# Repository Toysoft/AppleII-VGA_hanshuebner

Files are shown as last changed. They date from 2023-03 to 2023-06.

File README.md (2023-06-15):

# ∀2 Retro Computing Analog VGA Card & PicoPal
PicoPal Logo

This is a fork of
[David Kuder's version](https://github.com/V2RetroComputing/analog) of
[Mark Aikens' Apple II VGA](https://github.com/markadev/AppleII-VGA/)
project.

The goal of this fork is to make the board cheaper and easier to
produce.  It is now a 2 layer instead of a 4 layer PCB, uses cheaper
bus transceivers and 0603 passive components that are easier to work
with when building the board by hand.

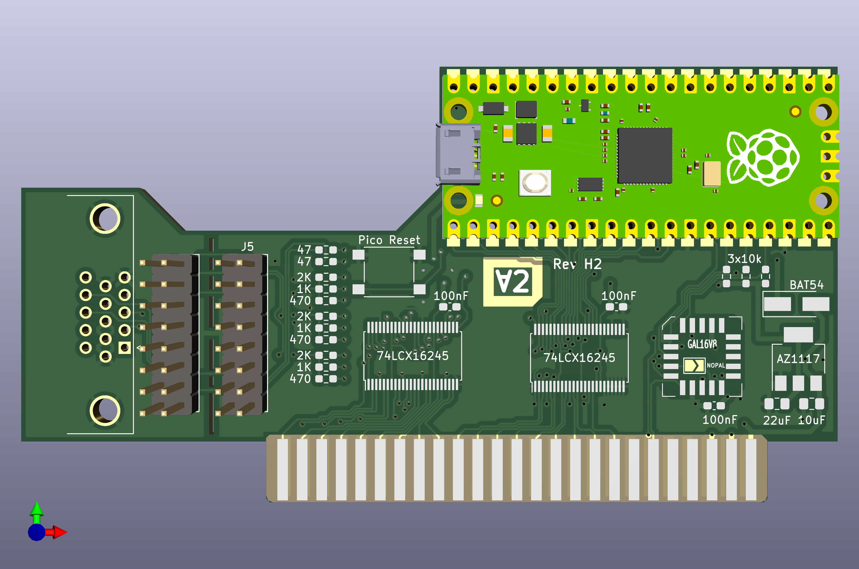
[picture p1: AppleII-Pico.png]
PCB Rendering


The board provides a VGA output to Apple II compatible machines.  It works by
snooping the bus activity and capturing what is written to the internal
graphics hardware.  This is used to render an additional image into a
framebuffer on the Raspberry Pi Pico.  That framebuffer is output
to a standard VGA compatible output.

The VGA emulation starts up with a test screen.  Reset your Apple to
go to the BASIC prompt or boot screen.

The footprint of the VGA IDC connector on the board is incorrect.  The
red wire of the ribbon cable must be facing down, in direction of the 
motherboard.  If you get no picture, try rotating the cable.

Alternatively, the card can run a Z80 emulation in software, emulating
a standard Z80 softcard.  To use that mode, the Raspberry Pi Pico must
be re-flashed.

Please use
[GitHub Issues](https://github.com/hanshuebner/AppleII-VGA/issues) to
provide feedback.  THANK YOU!

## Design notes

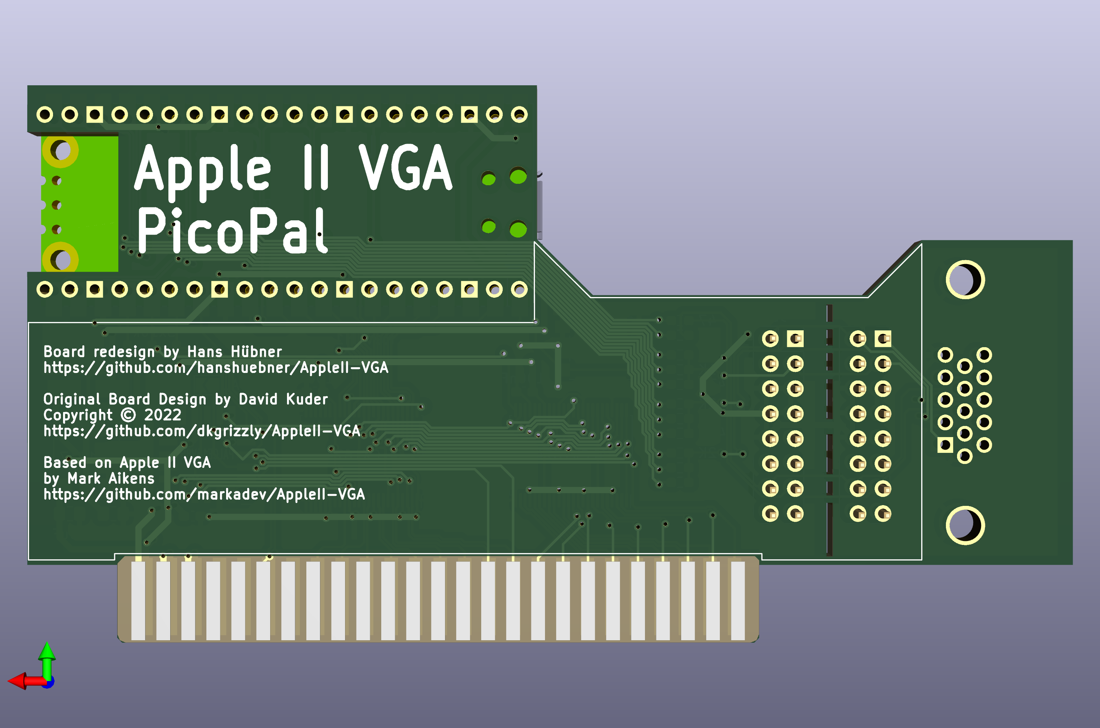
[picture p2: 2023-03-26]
docs/AppleII-Pico-back.png

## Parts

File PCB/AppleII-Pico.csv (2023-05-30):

Comment | Designator | Footprint | LCSC
100nF | C1,C2,C3 | Capacitor_SMD:C_0603_1608Metric_Pad1.08x0.95mm_HandSolder | C2857981
22uF | C10 | Capacitor_SMD:C_0805_2012Metric_Pad1.18x1.45mm_HandSolder | C5181863
10uF | C11 | Capacitor_SMD:C_0805_2012Metric_Pad1.18x1.45mm_HandSolder | C123608
BAT54 | D1 | Diode_SMD:D_SMA_Handsoldering | C5204731
Apple II | J1 | STDBUS:AppleII
DB15_Female_HighDensity_MountingHoles | J2 | Connector_Dsub:DSUB-15-HD_Female_Horizontal_P2.29x1.98mm_EdgePinOffset3.03mm_Housed_MountingHolesOffset4.94mm
NOGAL | J3 | Jumper:SolderJumper-2_P1.3mm_Open_TrianglePad1.0x1.5mm
VGA | J4,J5 | Connector_PinHeader_2.54mm:PinHeader_2x08_P2.54mm_Vertical
470 | R1,R4,R7 | Resistor_SMD:R_0603_1608Metric_Pad0.98x0.95mm_HandSolder | C103660
47 | R10,R11 | Resistor_SMD:R_0603_1608Metric_Pad0.98x0.95mm_HandSolder | C3016437
10K | R12,R13,R14 | Resistor_SMD:R_0603_1608Metric_Pad0.98x0.95mm_HandSolder | C3017715
1K | R2,R5,R8 | Resistor_SMD:R_0603_1608Metric_Pad0.98x0.95mm_HandSolder | C3016283
2K | R3,R6,R9 | Resistor_SMD:R_0603_1608Metric_Pad0.98x0.95mm_HandSolder | C3016472
Pico Reset | SW1 | Button_Switch_SMD:SW_Push_1P1T_NO_6x6mm_H9.5mm | C5381239
74LCX16245 | U1 | Package_SO:TSSOP-48_6.1x9.7mm_P0.4mm | C894789
74LCX16245 | U2 | Package_SO:TSSOP-48_6.1x12.5mm_P0.5mm | C894789
GAL16V8 | U5 | Package_LCC:PLCC-20
Pi PICO | U6 | MCU_RaspberryPi_and_Boards:RPi_Pico_SMD_TH
AZ1117-3.3 | U7 | Package_TO_SOT_SMD:SOT-223-3_TabPin2 | C110474

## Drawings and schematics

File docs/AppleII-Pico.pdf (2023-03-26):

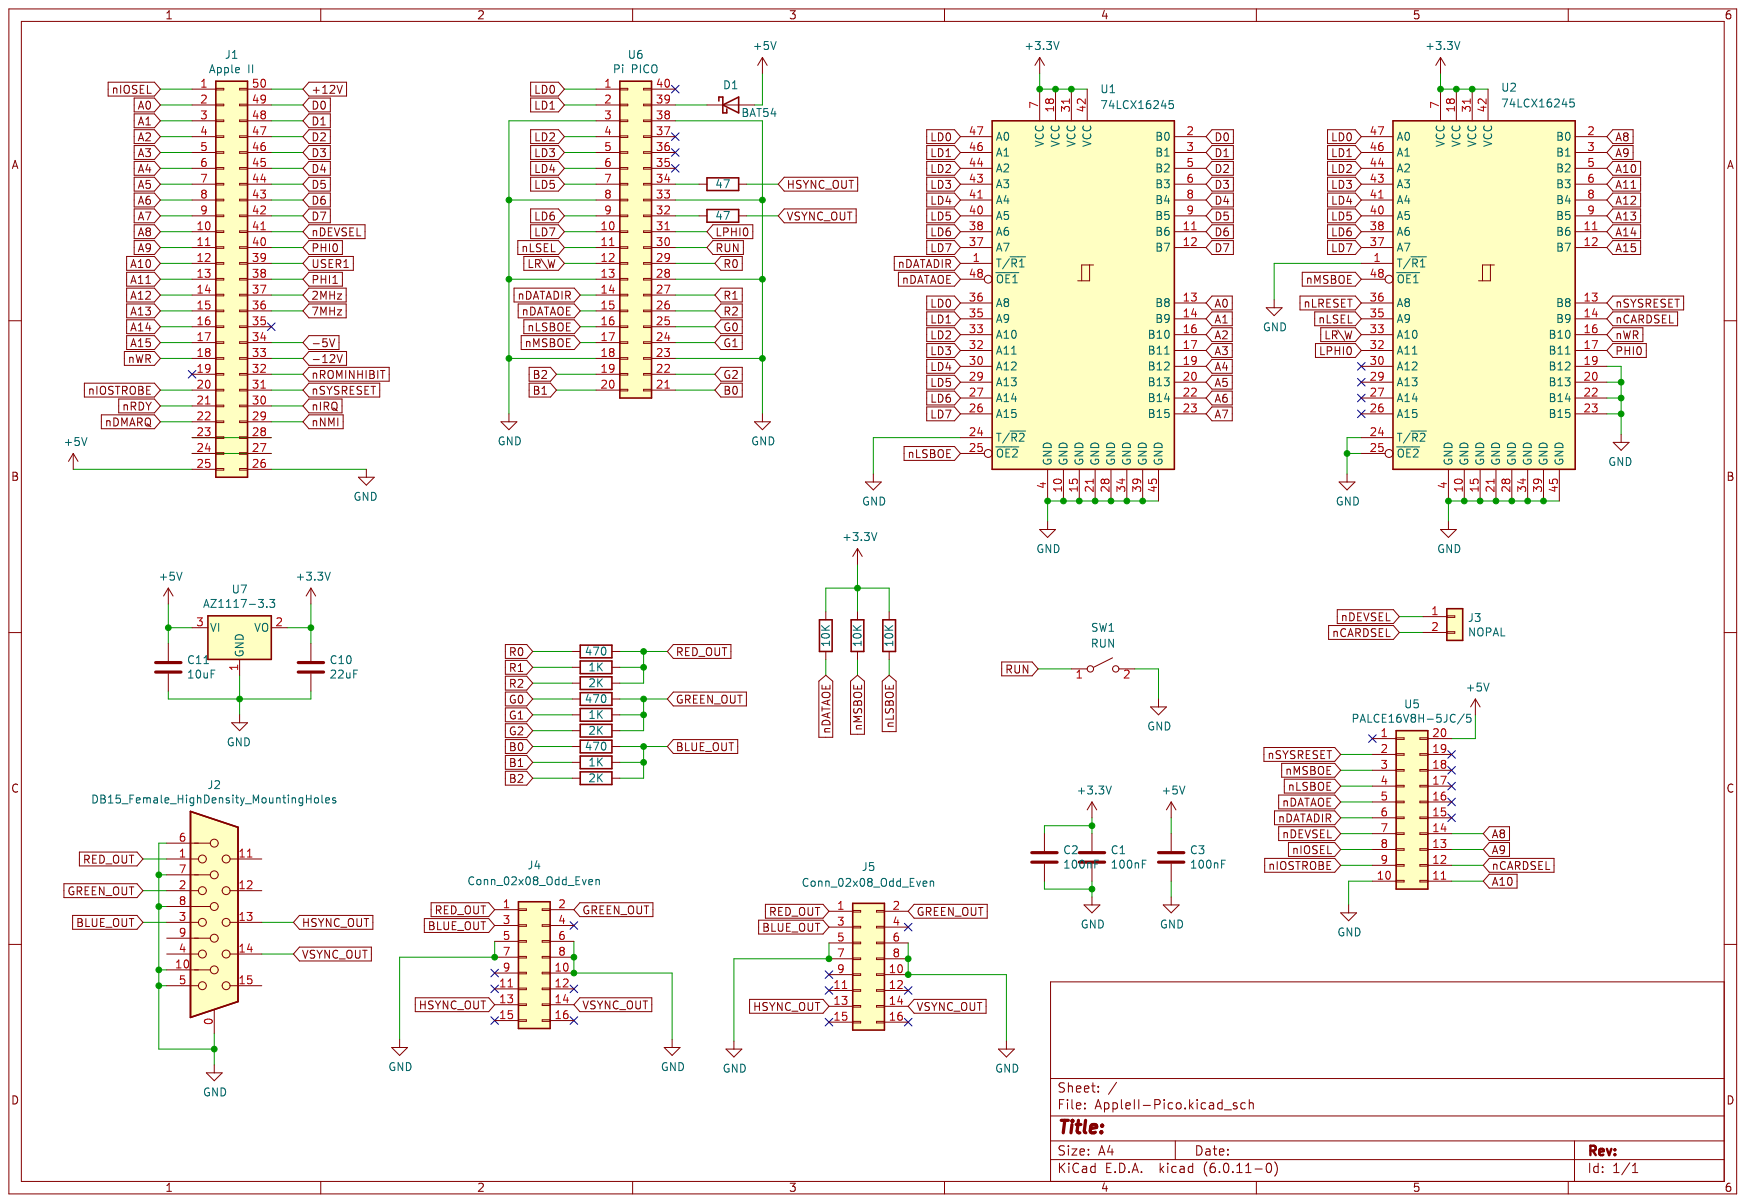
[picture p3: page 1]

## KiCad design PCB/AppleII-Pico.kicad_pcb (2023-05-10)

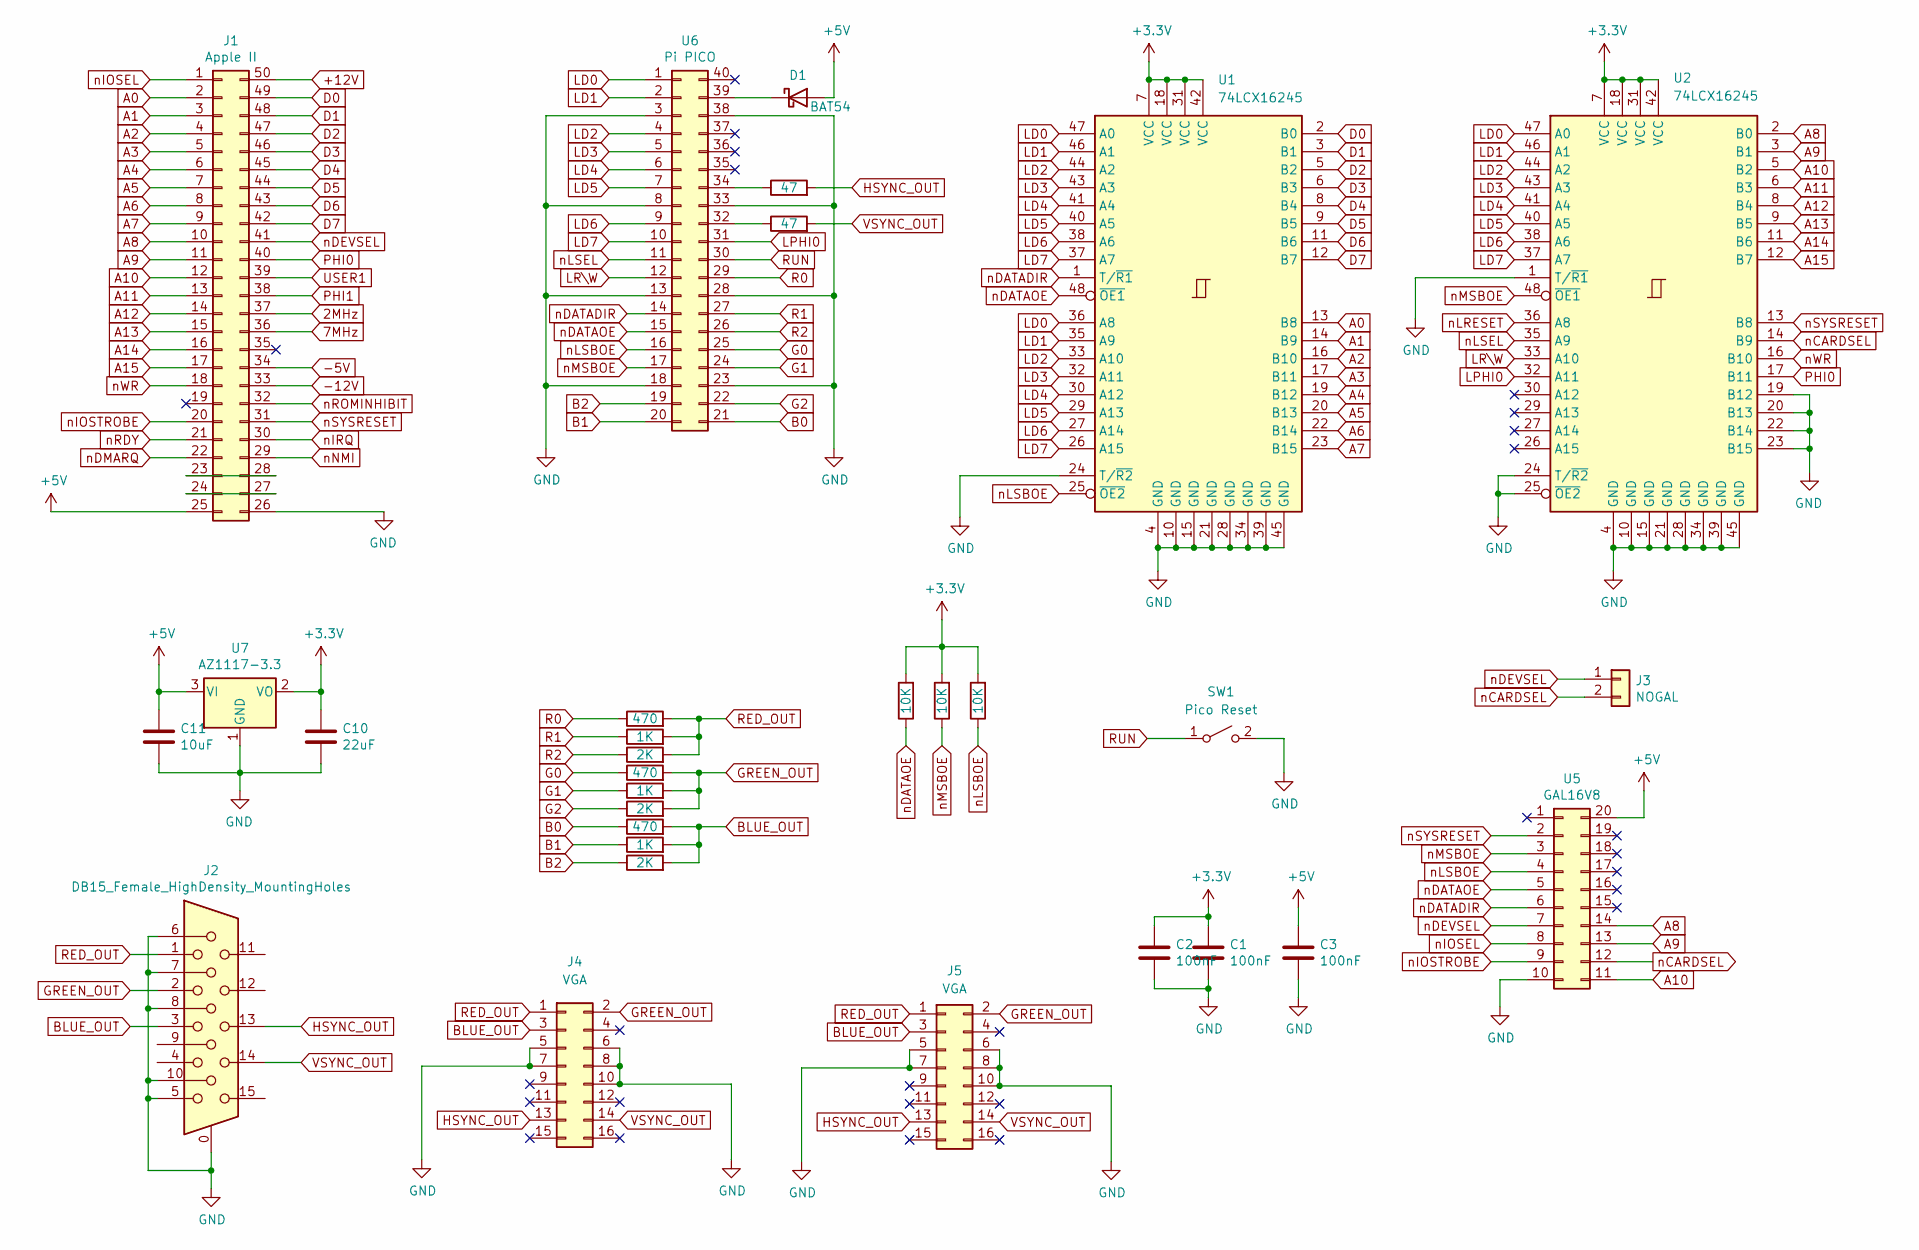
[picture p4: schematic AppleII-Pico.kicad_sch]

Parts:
C1, C2, C3: 100nF; C_0603_1608Metric_Pad1.08x0.95mm_HandSolder
C10: 22uF; C_0805_2012Metric_Pad1.18x1.45mm_HandSolder
C11: 10uF; C_0805_2012Metric_Pad1.18x1.45mm_HandSolder
D1: BAT54; D_SMA_Handsoldering
J1: Apple II; AppleII
J2: DB15_Female_HighDensity_MountingHoles; DSUB-15-HD_Female_Horizontal_P2.29x1.98mm_EdgePinOffset3.03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
J3: NOGAL; SolderJumper-2_P1.3mm_Open_TrianglePad1.0x1.5mm
J4, J5: VGA; PinHeader_2x08_P2.54mm_Vertical
R1, R4, R7: 470; R_0603_1608Metric_Pad0.98x0.95mm_HandSolder
R2, R5, R8: 1K; R_0603_1608Metric_Pad0.98x0.95mm_HandSolder
R3, R6, R9: 2K; R_0603_1608Metric_Pad0.98x0.95mm_HandSolder
R10, R11: 47; R_0603_1608Metric_Pad0.98x0.95mm_HandSolder
R12, R13, R14: 10K; R_0603_1608Metric_Pad0.98x0.95mm_HandSolder
SW1: Pico Reset; SW_Push_1P1T_NO_6x6mm_H9.5mm
U1: 74LCX16245; TSSOP-48_6.1x9.7mm_P0.4mm
U2: 74LCX16245; TSSOP-48_6.1x12.5mm_P0.5mm
U5: GAL16V8; PLCC-20
U6: Pi PICO; RPi_Pico_SMD_TH
U7: AZ1117-3.3; SOT-223-3_TabPin2

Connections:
2MHz: J1.37
7MHz: J1.36
+3V3: C1.1, C2.1, C10.1, R12.2, R13.2, R14.2, U1.7 (VCC), U1.18 (VCC), U1.31 (VCC), U1.42 (VCC), U2.7 (VCC), U2.18 (VCC), U2.31 (VCC), U2.42 (VCC), U7.2 (VO)
+5V: C3.1, C11.1, D1.2 (A), J1.25, U5.20, U7.3 (VI)
+12V: J1.50
-5V: J1.34
-12V: J1.33
A0: J1.2, U1.13 (B8)
A1: J1.3, U1.14 (B9)
A2: J1.4, U1.16 (B10)
A3: J1.5, U1.17 (B11)
A4: J1.6, U1.19 (B12)
A5: J1.7, U1.20 (B13)
A6: J1.8, U1.22 (B14)
A7: J1.9, U1.23 (B15)
A8: J1.10, U2.2 (B0), U5.14
A9: J1.11, U2.3 (B1), U5.13
A10: J1.12, U2.5 (B2), U5.11
A11: J1.13, U2.6 (B3)
A12: J1.14, U2.8 (B4)
A13: J1.15, U2.9 (B5)
A14: J1.16, U2.11 (B6)
A15: J1.17, U2.12 (B7)
B0: R7.1, U6.21
B1: R8.1, U6.20
B2: R9.1, U6.19
BLUE_OUT: J2.3, J4.3, J5.3, R7.2, R8.2, R9.2
D0: J1.49, U1.2 (B0)
D1: J1.48, U1.3 (B1)
D2: J1.47, U1.5 (B2)
D3: J1.46, U1.6 (B3)
D4: J1.45, U1.8 (B4)
D5: J1.44, U1.9 (B5)
D6: J1.43, U1.11 (B6)
D7: J1.42, U1.12 (B7)
G0: R4.1, U6.25
G1: R5.1, U6.24
G2: R6.1, U6.22
GND: C1.2, C2.2, C3.2, C10.2, C11.2, J1.26, J2.0, J2.5, J2.6, J2.7, J2.8, J2.10, J4.5, J4.6, J4.7, J4.8, J4.10, J5.5, J5.6, J5.7, J5.8, J5.10, SW1.2 (B), U1.4 (GND), U1.10 (GND), U1.15 (GND), U1.21 (GND), U1.24 (T/~R2), U1.28 (GND), U1.34 (GND), U1.39 (GND), U1.45 (GND), U2.1 (T/~R1), U2.4 (GND), U2.10 (GND), U2.15 (GND), U2.19 (B12), U2.20 (B13), U2.21 (GND), U2.22 (B14), U2.23 (B15), U2.24 (T/~R2), U2.25 (~OE2), U2.28 (GND), U2.34 (GND), U2.39 (GND), U2.45 (GND), U5.10, U6.3, U6.8, U6.13, U6.18, U6.23, U6.28, U6.33, U6.38, U7.1 (GND)
GREEN_OUT: J2.2, J4.2, J5.2, R4.2, R5.2, R6.2
HSYNC_OUT: J2.13, J4.13, J5.13, R10.2
LD0: U1.36 (A8), U1.47 (A0), U2.47 (A0), U6.1
LD1: U1.35 (A9), U1.46 (A1), U2.46 (A1), U6.2
LD2: U1.33 (A10), U1.44 (A2), U2.44 (A2), U6.4
LD3: U1.32 (A11), U1.43 (A3), U2.43 (A3), U6.5
LD4: U1.30 (A12), U1.41 (A4), U2.41 (A4), U6.6
LD5: U1.29 (A13), U1.40 (A5), U2.40 (A5), U6.7
LD6: U1.27 (A14), U1.38 (A6), U2.38 (A6), U6.9
LD7: U1.26 (A15), U1.37 (A7), U2.37 (A7), U6.10
LPHI0: U2.32 (A11), U6.31
LR\W: U2.33 (A10), U6.12
unnamed: D1.1 (K), U6.39
unnamed: J1.23, J1.28
unnamed: J1.24, J1.27
unnamed: R11.1, U6.32
unnamed: R10.1, U6.34
PHI0: J1.40, U2.17 (B11)
PHI1: J1.38
R0: R1.1, U6.29
R1: R2.1, U6.27
R2: R3.1, U6.26
RED_OUT: J2.1, J4.1, J5.1, R1.2, R2.2, R3.2
RUN: SW1.1 (A), U6.30
USER1: J1.39
VSYNC_OUT: J2.14, J4.14, J5.14, R11.2
nCARDSEL: J3.2, U2.14 (B9), U5.12
nDATADIR: U1.1 (T/~R1), U5.6, U6.14
nDATAOE: R12.1, U1.48 (~OE1), U5.5, U6.15
nDEVSEL: J1.41, J3.1, U5.7
nDMARQ: J1.22
nIOSEL: J1.1, U5.8
nIOSTROBE: J1.20, U5.9
nIRQ: J1.30
nLRESET: U2.36 (A8)
nLSBOE: R14.1, U1.25 (~OE2), U5.4, U6.16
nLSEL: U2.35 (A9), U6.11
nMSBOE: R13.1, U2.48 (~OE1), U5.3, U6.17
nNMI: J1.29
nRDY: J1.21
nROMINHIBIT: J1.32
nSYSRESET: J1.31, U2.13 (B8), U5.2
nWR: J1.18, U2.16 (B10)

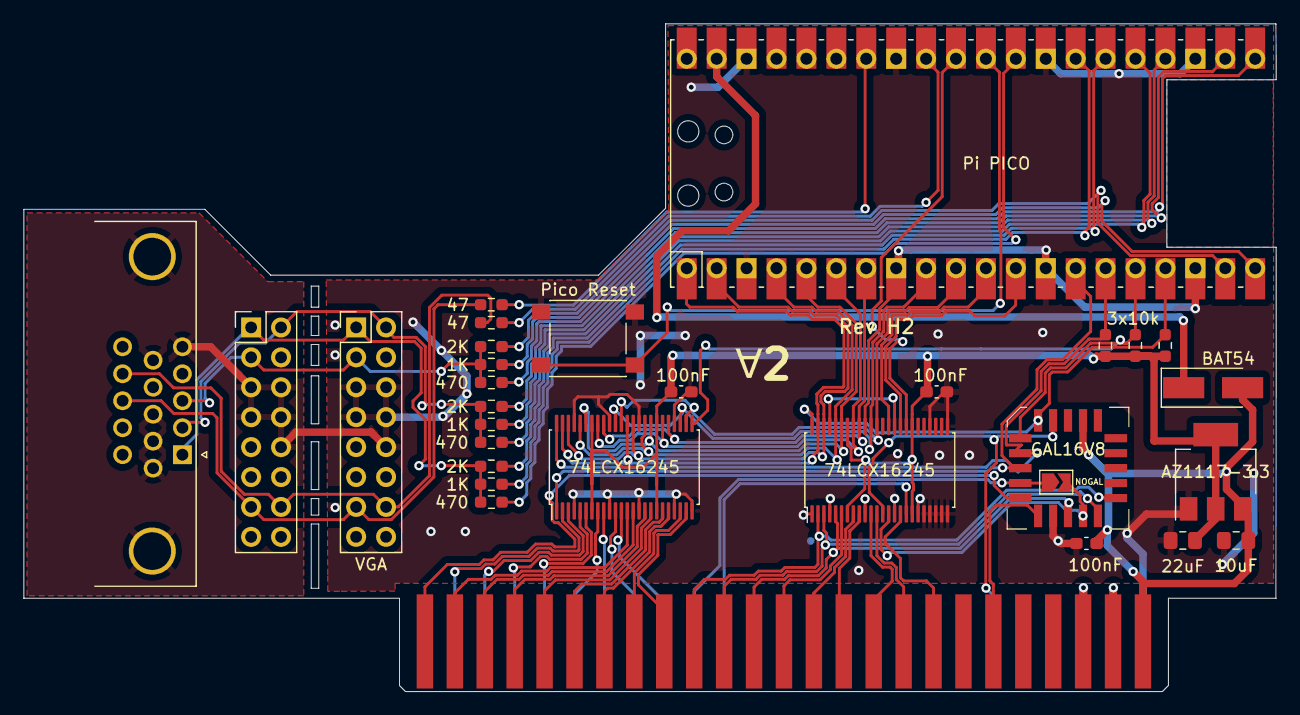
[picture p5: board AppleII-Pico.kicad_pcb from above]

Board: 2 copper layers, 106.3 x 56.7 mm, 31 parts (0 on the bottom side), 69 nets.

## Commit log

2023-03-25 Rework PCB to make it more DIY-friendly
    - Use 2 layer PCB
    - Replace bus transceivers by cheaper and easier to find 74LCX16245
    - Put component values on silkscreen
    - Replace 0402 passives with 0603's
    - Add IDC header for VGA breakout cable
    [AppleII-Pico-B_Cu.gbl, AppleII-Pico-B_Mask.gbs, AppleII-Pico-B_Paste.gbp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]
2023-03-25 Rename schematics file
2023-03-26 Make space for THT DIP socket
    [AppleII-Pico.kicad_pcb]
2023-03-26 Better RPi Pico footprint
    [AppleII-Pico.kicad_pcb, AppleII-Pico.kicad_sch]
2023-03-26 more space for the USB connector
    [AppleII-Pico.kicad_pcb]
2023-03-26 DRC fixes
    [AppleII-Pico.kicad_pcb]
2023-03-26 beauty tweaks
    [AppleII-Pico.kicad_pcb]
2023-03-26 incorporate feedback
    - Pico W antenna cutout
    - Pico RUN button
    - Break-away HD15A connector
    [AppleII-Pico.kicad_pcb, AppleII-Pico.kicad_sch]
2023-03-26 Update images and schematics PDF
2023-03-26 RUN => Pico Reset
    [AppleII-Pico.kicad_pcb, AppleII-Pico.kicad_sch]
2023-03-26 fix db15hd footprint
    [AppleII-Pico.kicad_pcb]
2023-03-26 Update gerber directory
    [AppleII-Pico.kicad_pcb]
2023-03-28 tweaks before sending to JLCPCB
    [AppleII-Pico.kicad_pcb]
2023-04-24 Fix TSSOP-48 footprint and move NOPAL
    - Use correct footprint for the TSSOP-48 case (closes #2)
    - Rename NOPAL to NOGAL and move it into the GAL footprint (closes #3)
    [AppleII-Pico.kicad_pcb, AppleII-Pico.kicad_sch]
2023-04-27 silkscreen tweaks
    closes #4
    [AppleII-Pico.kicad_pcb, AppleII-Pico.kicad_sch]
2023-05-10 Version h2 sent to JLCPCB for production
    [AppleII-Pico.kicad_pcb, AppleII-Pico.kicad_sch]
2023-05-30 Add BOM and production files
    [AppleII-Pico.csv, AppleII-Pico.kicad_sch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]

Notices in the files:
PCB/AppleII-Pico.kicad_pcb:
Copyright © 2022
